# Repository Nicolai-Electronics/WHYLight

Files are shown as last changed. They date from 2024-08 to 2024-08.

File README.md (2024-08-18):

# WHYlight
Hardware design files for the WHYlight project.

A PoE+ powered addressable LED strip driver using an ESP32-C6.

## Features
 - 100mbit ethernet
 - PoE+ powered
 - WiFi / BLE / 802.15.4 radio
 - LoRa radio
 - Suitable for both single and dual wire addressable LEDs
 - TTL differential output for DMX

## License

Copyright 2024 Nicolai Electronics

This project is licensed [CERN-OHL-P](license.txt).

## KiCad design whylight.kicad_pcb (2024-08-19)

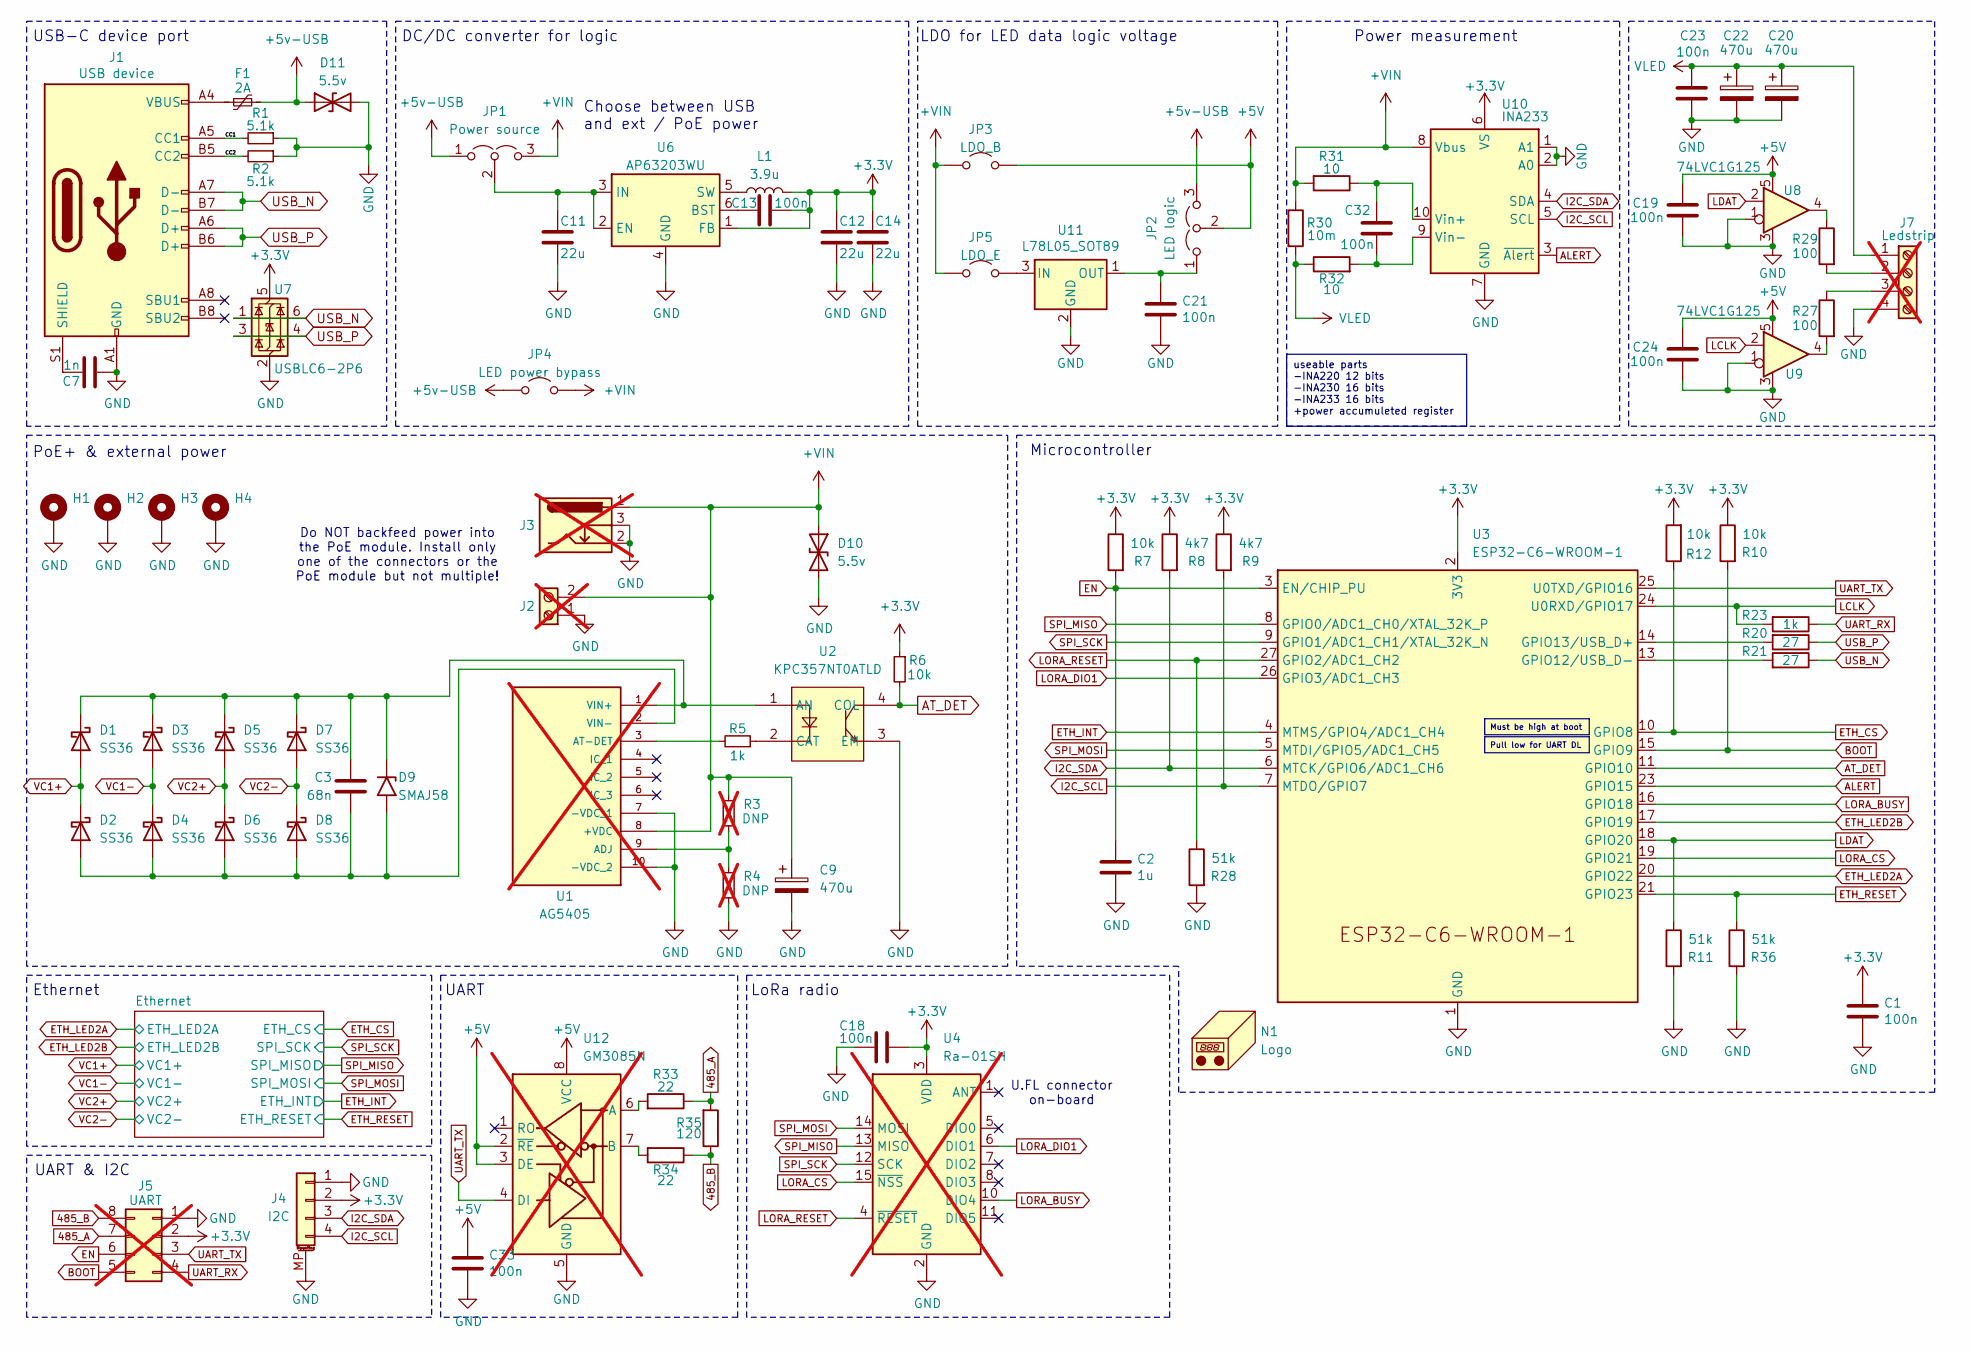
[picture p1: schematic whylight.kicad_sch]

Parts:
C1, C13, C18, C19, C21, C23, C24, C32, C33: 100n; C_0402_1005Metric; LCSC C394158
C2: 1u; C_0402_1005Metric; LCSC C5137485
C3: 68n; C_0402_1005Metric; LCSC C565562
C7: 1n; C_1206_3216Metric; LCSC C2173292
C9, C20, C22: 470u; CP_Elec_8x10; LCSC C2164331
C11, C12, C14: 22u; C_0805_2012Metric; LCSC C45783
D1, D2, D3, D4, D5, D6, D7, D8: SS36; D_SMA; LCSC C727061
D9: SMAJ58; D_SMA; LCSC C132935
D10, D11: 5.5v; D_SOD-323; LCSC C19224
F1: 2A; Fuse_0805_2012Metric; LCSC C70158
H1, H2, H3, H4: MountingHole_2.2mm_M2_DIN965_Pad
J1: USB device; USB_C_Receptacle_HRO_TYPE-C-31-M-12; LCSC C165948
J2: External 5v; PhoenixContact_MC_1,5_2-G-5.08_1x02_P5.08mm_Horizontal; LCSC C5188463; not fitted
J3: External 5v; BarrelJack_GCT_DCJ200-10-A_Horizontal; LCSC C381116; not fitted
J4: I2C; JST_SH_BM04B-SRSS-TB_1x04-1MP_P1.00mm_Vertical; LCSC C160390
J5: UART; PinHeader_2x04_P2.54mm_Vertical; not fitted
J7: Ledstrip; PhoenixContact_MC_1,5_4-GF-5.08_1x04_P5.08mm_Horizontal_Thr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; not fitted
JP1: Power source; SolderJumper-3_P1.3mm_Open_RoundedPad1.0x1.5mm_NumberLabels
JP2: LED logic; SolderJumper-3_P1.3mm_Open_RoundedPad1.0x1.5mm_NumberLabels
JP3: LDO_B; SolderJumper-2_P1.3mm_Open_RoundedPad1.0x1.5mm
JP4: LED power bypass; SolderJumper-2_P1.3mm_Open_RoundedPad1.0x1.5mm
JP5: LDO_E; SolderJumper-2_P1.3mm_Open_RoundedPad1.0x1.5mm
L1: 3.9u; L_Coilcraft_XAL5050-XXX; LCSC C167928
N1: Logo; logo_nicolai
R1, R2: 5.1k; R_0402_1005Metric; LCSC C25905
R3, R4: DNP; R_0402_1005Metric; not fitted
R5, R23: 1k; R_0402_1005Metric; LCSC C11702
R6, R7, R10, R12: 10k; R_0402_1005Metric; LCSC C60490
R8, R9: 4k7; R_0402_1005Metric; LCSC C25900
R11, R28, R36: 51k; R_0402_1005Metric; LCSC C25794
R20, R21: 27; R_0402_1005Metric; LCSC C25100
R27, R29: 100; R_0402_1005Metric; LCSC C25076
R30: 10m; R_1206_3216Metric; LCSC C105362
R31, R32: 10; R_0402_1005Metric; LCSC C138066
R33, R34: 22; R_0402_1005Metric; LCSC C25092
R35: 120; R_0402_1005Metric; LCSC C25079
U1: AG5405; AG5300; not fitted
U2: KPC357NT0ATLD; SOP-4_L3.9-W4.4-P2.54-LS7.0-BR; LCSC C136410
U3: ESP32-C6-WROOM-1; LCSC C5366877
U4: Ra-01SH; Ai-Thinker-Ra-01-LoRa; not fitted
U6: AP63203WU; TSOT-23-6; LCSC C780769
U7: USBLC6-2P6; SOT-666; LCSC C2827693
U8, U9: 74LVC1G125; SOT-353_SC-70-5; LCSC C12519
U10: INA233; VSSOP-10_3x3mm_P0.5mm; LCSC C2653838
U11: L78L05_SOT89; SOT-89-3; LCSC C408272
U12: GM3085N; SOIC-8_3.9x4.9mm_P1.27mm; LCSC C269865; not fitted

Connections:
485_A: J5.7, R33.1, R35.2
485_B: J5.8, R34.1, R35.1
+3.3V: C1.1, C12.1, C13.1, C14.1, C18.1, J4.2, J5.2, L1.2, R6.1, R7.1, R8.1, R9.1, R10.1, R12.2, U3.2 (3V3), U4.3 (VDD), U6.1 (FB), U7.5 (VBUS), U10.6 (VS); also elsewhere on the board
+5V: C19.2, C24.2, C33.1, JP2.2 (C), JP3.2 (B), U8.5 (VCC), U9.5 (VCC), U12.2 (~RE), U12.3 (DE), U12.8 (VCC)
+5v-USB: D11.1 (A1), F1.1, JP1.1 (A), JP2.3 (B), JP4.1 (A)
+VIN: C9.1, D10.1 (A1), J2.2, J3.1, JP1.3 (B), JP3.1 (A), JP4.2 (B), JP5.1 (A), R3.2, R30.1, R31.2, U1.8 (+VDC), U10.8 (Vbus)
/CC1: J1.A5 (CC1), R1.2
/CC2: J1.B5 (CC2), R2.2
ALERT: U3.23 (GPIO15), U10.3 (~Alert)
AT_DET: R6.2, U2.4 (COL), U3.11 (GPIO10)
BOOT: J5.5, R10.2, U3.15 (GPIO9)
EN: C2.1, J5.6, R7.2, U3.3 (EN/CHIP_PU)
ETH_CS: R12.1, U3.10 (GPIO8); also elsewhere on the board
ETH_INT: U3.4 (MTMS/GPIO4/ADC1_CH4); also elsewhere on the board
ETH_LED2A: U3.20 (GPIO22); also elsewhere on the board
ETH_LED2B: U3.17 (GPIO19); also elsewhere on the board
ETH_RESET: R36.1, U3.21 (GPIO23); also elsewhere on the board
GND: C1.2, C2.2, C7.2, C9.2, C11.2, C12.2, C14.2, C18.2, C19.1, C20.2, C21.2, C22.2, C23.2, C24.1, C33.2, D10.2 (A2), D11.2 (A2), H1.1, H2.1, H3.1, H4.1, J1.A1 (GND), J1.A12 (GND), J1.B1 (GND), J1.B12 (GND), J2.1, J3.2, J3.3, J4.1, J4.MP (MountPin), J5.1, J7.4, R1.1, R2.1, R4.1, R11.2, R28.2, R36.2, U1.7 (-VDC_1), U1.10 (-VDC_2), U2.3 (EM), U3.1 (GND), U3.12 (GPIO11), U3.28 (GND), U3.29 (GND), U4.2 (GND), U4.9 (GND), U4.16 (GND), U6.4 (GND), U7.2 (GND), U8.1, U8.3 (GND), U9.1, U9.3 (GND), U10.1 (A1), U10.2 (A0), U10.7 (GND), U11.2 (GND), U12.5 (GND); also elsewhere on the board
I2C_SCL: J4.4, R9.2, U3.7 (MTDO/GPIO7), U10.5 (SCL)
I2C_SDA: J4.3, R8.2, U3.6 (MTCK/GPIO6/ADC1_CH6), U10.4 (SDA)
LCLK: R23.2, U3.24 (U0RXD/GPIO17), U9.2
LDAT: R11.1, U3.18 (GPIO20), U8.2
LORA_BUSY: U3.16 (GPIO18), U4.10 (DIO4)
LORA_CS: U3.19 (GPIO21), U4.15 (~NSS)
LORA_DIO1: U3.26 (GPIO3/ADC1_CH3), U4.6 (DIO1)
LORA_RESET: R28.1, U3.27 (GPIO2/ADC1_CH2), U4.4 (~RESET)
unnamed: C3.1, D1.1 (K), D3.1 (K), D5.1 (K), D7.1 (K), D9.1 (A1), U1.1 (VIN+), U2.1 (AN)
unnamed: C3.2, D2.2 (A), D4.2 (A), D6.2 (A), D8.2 (A), D9.2 (A2), U1.2 (VIN-)
unnamed: F1.2, J1.A4 (VBUS), J1.A9 (VBUS), J1.B4 (VBUS), J1.B9 (VBUS)
unnamed: C7.1, J1.S1 (SHIELD)
unnamed: J7.2, R29.2
unnamed: J7.3, R27.1
unnamed: C11.1, JP1.2 (C), U6.2 (EN), U6.3 (IN)
unnamed: C21.1, JP2.1 (A), U11.1 (OUT)
unnamed: JP5.2 (B), U11.3 (IN)
unnamed: R27.2, U9.4
unnamed: R29.1, U8.4
unnamed: R3.1, R4.2, U1.9 (ADJ)
unnamed: R5.2, U1.3 (AT-DET)
unnamed: R5.1, U2.2 (CAT)
unnamed: R21.2, U3.13 (GPIO12/USB_D-)
unnamed: R20.2, U3.14 (GPIO13/USB_D+)
unnamed: C13.2, U6.6 (BST)
unnamed: L1.1, U6.5 (SW)
unnamed: C32.2, R31.1, U10.10 (Vin+)
unnamed: C32.1, R32.2, U10.9 (Vin-)
unnamed: R33.2, U12.6 (A)
unnamed: R34.2, U12.7 (B)
SPI_MISO: U3.8 (GPIO0/ADC1_CH0/XTAL_32K_P), U4.13 (MISO); also elsewhere on the board
SPI_MOSI: U3.5 (MTDI/GPIO5/ADC1_CH5), U4.14 (MOSI); also elsewhere on the board
SPI_SCK: U3.9 (GPIO1/ADC1_CH1/XTAL_32K_N), U4.12 (SCK); also elsewhere on the board
UART_RX: J5.4, R23.1
UART_TX: J5.3, U3.25 (U0TXD/GPIO16), U12.4 (DI)
USB_N: J1.A7 (D-), J1.B7 (D-), R21.1, U7.1 (I/O1), U7.6 (I/O1)
USB_P: J1.A6 (D+), J1.B6 (D+), R20.1, U7.3 (I/O2), U7.4 (I/O2)
VC1+: D1.2 (A), D2.1 (K); also elsewhere on the board
VC1-: D3.2 (A), D4.1 (K); also elsewhere on the board
VC2+: D5.2 (A), D6.1 (K); also elsewhere on the board
VC2-: D7.2 (A), D8.1 (K); also elsewhere on the board
VLED: C20.1, C22.1, C23.1, J7.1, R30.2, R32.1

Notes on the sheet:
Pull low for UART DL
Must be high at boot
useable parts -INA220 12 bits -INA230 16 bits -INA233 16 bits +power accumuleted register
Ethernet
Choose between USB and ext / PoE power
USB-C device port
Microcontroller
Power measurement
UART
DC/DC converter for logic
U.FL connector on-board
LoRa radio
PoE+ & external power
LDO for LED data logic voltage
UART & I2C
Do NOT backfeed power into the PoE module. Install only one of the connectors or the PoE module but not multiple!

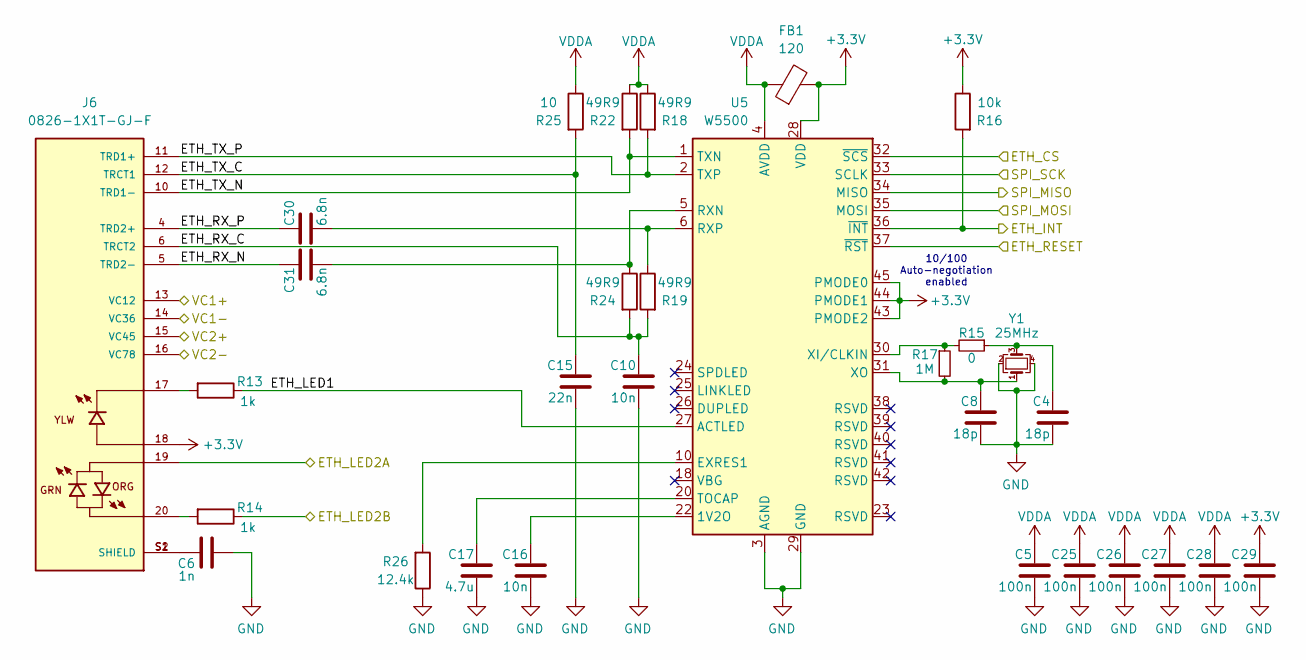
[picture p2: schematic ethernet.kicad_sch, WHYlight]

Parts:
C4, C8: 18p; C_0402_1005Metric; LCSC C555395
C5, C25, C26, C27, C28, C29: 100n; C_0402_1005Metric; LCSC C394158
C6: 1n; C_1206_3216Metric; LCSC C2173292
C10, C16: 10n; C_0402_1005Metric; LCSC C2875126
C15: 22n; C_0402_1005Metric; LCSC C466237
C17: 4.7u; C_0402_1005Metric; LCSC C307423
C30, C31: 6.8n; C_0402_1005Metric; LCSC C2760541
FB1: 120; L_0603_1608Metric; LCSC C709642
J6: 0826-1X1T-GJ-F; BEL_0826-1X1T-GJ-F
R13, R14: 1k; R_0402_1005Metric; LCSC C11702
R15: 0; R_0402_1005Metric; LCSC C17168
R16: 10k; R_0402_1005Metric; LCSC C60490
R17: 1M; R_0402_1005Metric; LCSC C26083
R18, R19, R22, R24: 49R9; R_0402_1005Metric; LCSC C25120
R25: 10; R_0402_1005Metric; LCSC C138066
R26: 12.4k; R_0402_1005Metric; LCSC C284314
U5: W5500; LQFP-48_7x7mm_P0.5mm; LCSC C32843
Y1: 25MHz; Crystal_SMD_3225-4Pin_3.2x2.5mm; LCSC C7424735

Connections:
+3.3V: C29.1, FB1.2, J6.18, R16.1, U5.28 (VDD), U5.43 (PMODE2), U5.44 (PMODE1), U5.45 (PMODE0); also elsewhere on the board
/Ethernet/ETH_LED1: R13.1, U5.27 (ACTLED)
/Ethernet/ETH_RX_C: C10.1, J6.6 (TRCT2), R19.2, R24.2
/Ethernet/ETH_RX_N: C31.1, J6.5 (TRD2-)
/Ethernet/ETH_RX_P: C30.1, J6.4 (TRD2+)
/Ethernet/ETH_TX_C: C15.1, J6.12 (TRCT1), R25.2
/Ethernet/ETH_TX_N: J6.10 (TRD1-), R22.2, U5.1 (TXN)
/Ethernet/ETH_TX_P: J6.11 (TRD1+), R18.2, U5.2 (TXP)
ETH_CS: U5.32 (~SCS); also elsewhere on the board
ETH_INT: R16.2, U5.36 (~INT); also elsewhere on the board
ETH_LED2A: J6.19; also elsewhere on the board
ETH_LED2B: R14.1; also elsewhere on the board
ETH_RESET: U5.37 (~RST); also elsewhere on the board
GND: C4.2, C5.2, C6.2, C8.2, C10.2, C15.2, C16.2, C17.2, C25.2, C26.2, C27.2, C28.2, C29.2, R26.1, U5.3 (AGND), U5.9 (AGND), U5.14 (AGND), U5.16 (AGND), U5.19 (AGND), U5.29 (GND), U5.48 (AGND), Y1.2, Y1.4; also elsewhere on the board
unnamed: C4.1, R15.1, Y1.3
unnamed: C6.1, J6.S1 (SHIELD), J6.S2 (SHIELD)
unnamed: J6.17, R13.2
unnamed: J6.20, R14.2
unnamed: C16.1, U5.22 (1V2O)
unnamed: R26.2, U5.10 (EXRES1)
unnamed: C31.2, R24.1, U5.5 (RXN)
unnamed: C30.2, R19.1, U5.6 (RXP)
unnamed: C17.1, U5.20 (TOCAP)
unnamed: R15.2, R17.1, U5.30 (XI/CLKIN)
unnamed: C8.1, R17.2, U5.31 (XO), Y1.1
SPI_MISO: U5.34 (MISO); also elsewhere on the board
SPI_MOSI: U5.35 (MOSI); also elsewhere on the board
SPI_SCK: U5.33 (SCLK); also elsewhere on the board
VC1+: J6.13 (VC12); also elsewhere on the board
VC1-: J6.14 (VC36); also elsewhere on the board
VC2+: J6.15 (VC45); also elsewhere on the board
VC2-: J6.16 (VC78); also elsewhere on the board
VDDA: C5.1, C25.1, C26.1, C27.1, C28.1, FB1.1, R18.1, R22.1, R25.1, U5.4 (AVDD), U5.8 (AVDD), U5.11 (AVDD), U5.15 (AVDD), U5.17 (AVDD), U5.21 (AVDD)

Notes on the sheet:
10/100 Auto-negotiation enabled

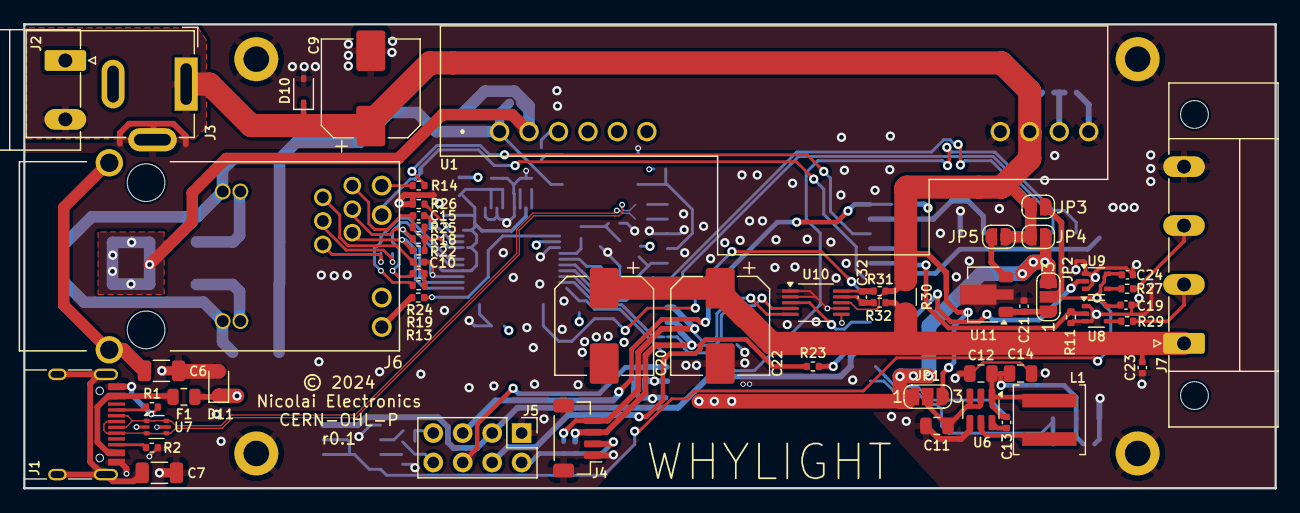
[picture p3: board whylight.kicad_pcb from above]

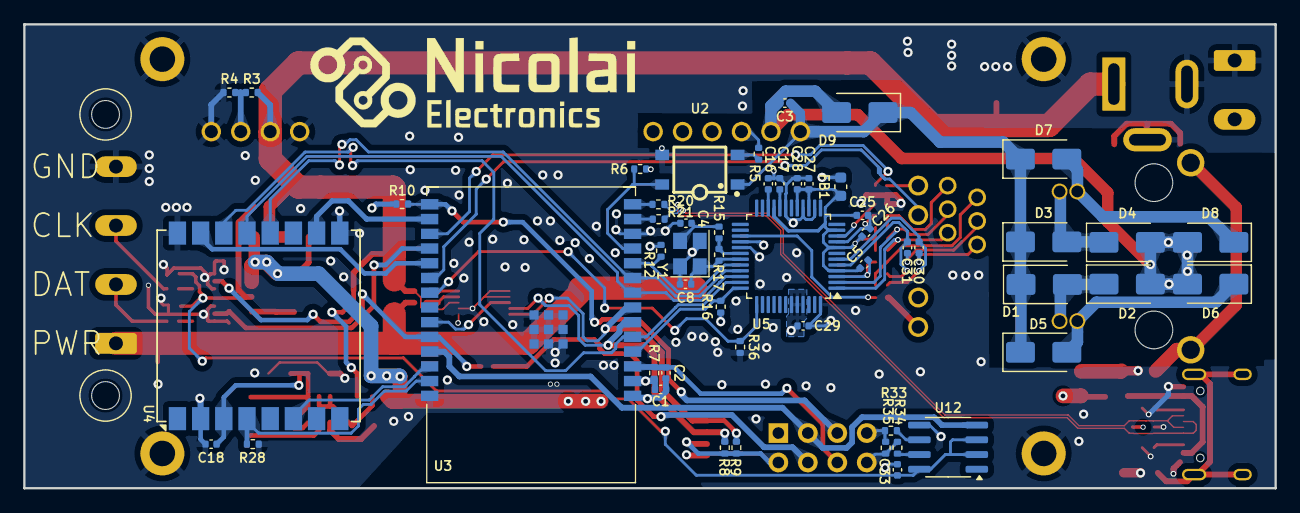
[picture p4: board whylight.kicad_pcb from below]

Board: 4 copper layers, 107.9 x 40.0 mm, 113 parts (53 on the bottom side), 79 nets.

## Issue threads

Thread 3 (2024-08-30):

D10 will cause problems when assembling for 12/24v operation

renzenicolai, 2024-08-30:

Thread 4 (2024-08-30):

Add solder jumper for selecting between external power and PoE+ module

renzenicolai, 2024-08-30:
... to prevent damage when someone assembles both

renzenicolai, 2024-08-31:
Or maybe add some smart ideal diode stuff to make the device work with both, could be helpful in the field to have only one type.

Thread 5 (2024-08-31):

LED data buffers don't work with 3.3v input

renzenicolai, 2024-08-31:
https://www.lcsc.com/product-detail/Buffer-Driver-Transceiver_Nexperia-74LVC1G17GW-125_C426705.html

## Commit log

2024-06-29 Fixes & add voltage/current monitor chip
    [whylight.kicad_pcb, whylight.kicad_sch]
2024-08-05 added 3D models, added LCSC numbers, added caps in RX line ethernet as per the datasheet, change crystal and capacitors to correctly match w5500 as per the datasheet, added bead to filter analoge pow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
    [ethernet.kicad_sch, whylight.kicad_pcb, whylight.kicad_sch]
2024-08-15 Change pinout of C6 to more closely resemble the WHY2025 badge
    [ethernet.kicad_sch, whylight.kicad_pcb, whylight.kicad_sch]
2024-08-17 Add RS485, add mounting holes, route more stuff
    [ethernet.kicad_sch, whylight.kicad_pcb, whylight.kicad_sch]
2024-08-18 Finish first pass of routing
    [whylight.kicad_pcb, whylight.kicad_sch]
2024-08-18 Rerouted power to where there is more space, solved issue with diff pair.
    [whylight.kicad_pcb]
2024-08-19 Release r0.1
    [ethernet.kicad_sch, whylight.kicad_pcb, whylight.kicad_sch]

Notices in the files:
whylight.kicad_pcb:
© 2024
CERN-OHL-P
